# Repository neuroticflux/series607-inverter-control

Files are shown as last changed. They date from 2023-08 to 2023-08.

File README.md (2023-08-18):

# series607-inverter-control

### Overview
#### What is this?
The Series607 Inverter Control is an Arduino-based device providing data logging and remote control of a Series 607 inverter (Found in Sweden at Kjell &amp; Co under the brand LuxorParts).
The Series 607 comes with a wired control panel showing power draw on the AC side and voltage on the DC side. The device described in this repository hijacks the communication bus going to the control panel and decodes the data, then reports it via Modbus to a master device, such as a Victron Cerbo GX, or a Raspberry Pi running VenusOS. It even lets you remotely turn the inverter on or off from the touch menu, and reports alarms and fault codes like undervoltage, overvoltage, overheating etc. :)



#### Disclaimer
If you want to try this out with your own Series 607 inverter, feel free! Of course I take no responsibility for what happens to you or your hardware if you use any material or information provided in this repository. You should always be careful around high voltages and high currents. There is NO NEED to get anywhere near the AC side outlets while building this project, and there is ABSOLUTELY NO NEED to open up the inverter itself.

#### RJ12 cable pinout:
Both the pinout and color codes may very well be different on different units, so always double-check before you plug in your expensive equipment that you have your wires hooked up right!

- PIN1 (blue): power switch
- PIN2 (black): +12V
- PIN3 (red): GND
- PIN4 (green): DATA
- PIN5 (yellow): CS
- PIN6 (brown): CLK

### Instructions

#### Hardware
You need an Arduino (I've tested on Uno and the prototype runs on a Micro, likely any ATmega328-based board will work) and some RS232-to-USB bridge like an FTDI breakout board or dongle. It needs to show up in VenusOS as /dev/ttyUSB*, so using the built-in USB port on the Arduinos doesn't work. If anyone can figure out how to set VenusOS up so it scans /dev/ttyACM* as well, please let me know. :)

You also need one PNP and one NPN transistor - 2N3904 and 2N3906 work fine - and two 10kohm resistors. There's a schematic under /pcb but it's not up to date. Check the Falstad link below for a schematic of the high side switch circuit you need for remote on/off switching in VenusOS to work, the rest should be fairly self-explanatory. Pin 1 (power switch) goes to the collector of the PNP, Pin 2 (+12V) goes to the emitter.
Pins 4, 5, and 6 go to the SPI MOSI, CS and CLK pins on the Arduino, and Arduino Pin 4 goes to the base of the NPN.
If you have an Arduino Micro, you can use the hardware serial port to interface with the FTDI board. The sketch in the repo is already set up for that. If you have a Uno or some other Arduino-style board, you might need to alter the code to set up a SoftwareSerial port on two of the digital pins and connect those to the FTDI.

The circuit is simple enough to deadbug, or stick it on a protoboard with fancy pin headers if you want. :)
Burn the sketch to the Arduino and connect it to the inverter according to the pinout.

DON'T GET +12V NEAR THE GPIO LINES! It will fry your microcontroller. Yes, it's happened to me, more than once. :P

#### VenusOS
Make sure you have superuser access to your Victron device, and a way to get files onto it (wget works fine I guess).
Put the series607.py script in /opt/victronenergy/dbus-modbus-client/, then edit the dbus-modbus-client.py script in that same folder. Add this line to the list of imports:
```Python
import series607
```
Now, when you connect the interface using the RS232 dongle, a new device called 'Series607 FSW Inverter' should show up in your VenusOS menu. It may take a minute for the TTY poller to run, so be patient. ;)

If you've gotten the pinout and high-side switch right, you should now be able to control your inverter and get DC-side voltage and AC-side power showing up.

### Technical

Simulating the high side BJT switch circuit in Falstad:
https://tinyurl.com/24upg6vq

TODO: Schematics/images

### Compatibility
I've only been able to find these inverters here in Sweden, but I'd love to know if there are similar products out there with the same or similar connectivity that could be hacked in this way. Feel free to post an issue if you have a question or can provide information, or a pull request if you have something to add like code or revised/improved hardware.

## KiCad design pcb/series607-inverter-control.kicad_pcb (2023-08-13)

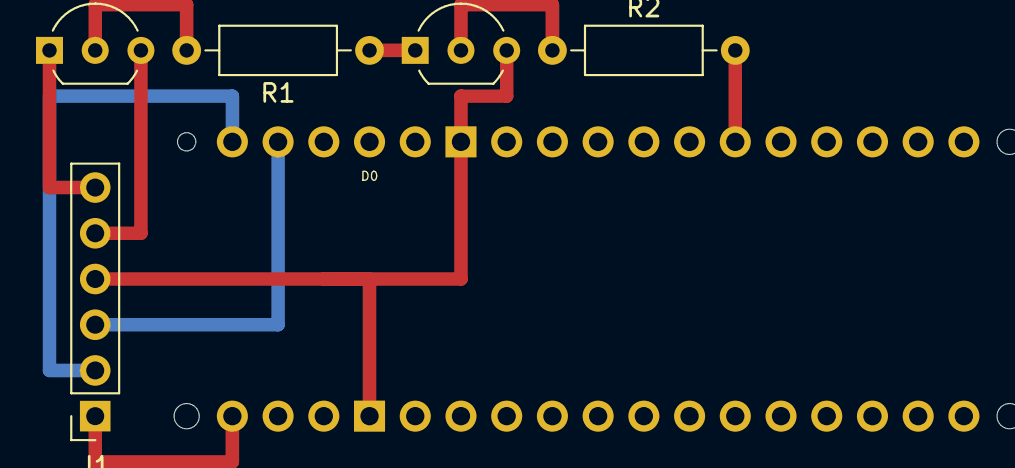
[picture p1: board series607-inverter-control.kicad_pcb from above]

Board: 2 copper layers, 6 parts (1 on the bottom side), 10 nets.

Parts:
A1: Arduino_Micro_Socket
J1: Conn_01x06_Pin; PinSocket_1x06_P2.54mm_Vertical
Q1: 2N3904; TO-92_Inline_Wide
Q2: 2N3906; TO-92_Inline_Wide
R1, R2: 10k; R_Axial_DIN0207_L6.3mm_D2.5mm_P10.16mm_Horizontal

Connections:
Arduino_GND: A1.GND1 (GND), A1.GND2 (GND), J1.4, Q1.3 (C)
Arduino_Pin_7: A1.D7 (D7_INT4), R2.2
Arduino_Pin_10: A1.SS (SPI_CS), J1.3
Arduino_Pin_11: A1.MOSI (SPI_MOSI), J1.2
Arduino_Pin_13: A1.SCK (SPI_SCK), J1.1
unnamed: J1.5, Q2.3 (C)
unnamed: J1.6, Q2.1 (E)
unnamed: Q1.2 (B), R2.1
unnamed: Q1.1 (E), R1.1
unnamed: Q2.2 (B), R1.2

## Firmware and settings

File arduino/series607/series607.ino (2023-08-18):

// Series 607 Inverter Arduino Interface
// Andy Christiansson (@neuroticflux) 2023-08-15

// Check out the repo at https://github.com/neuroticflux/series607-inverter-control for details and the latest version.

// This sketch lets an Arduino microcontroller interface with a Series 607 PSW inverter (like those sold by Kjell & Co in Sweden),
// effectively hijacking the LCD remote protocol to read power and voltage values, and, with a simple external circuit,
// allows the Arduino to remotely turn the inverter on and off.

// The interface speaks Modbus (currently over software serial port) and,
// with the accompanying Python script, can be used from a Victron Cerbo GX,
// a Raspberry Pi or other hardware running Venus OS.

// Depends on ModbusSerial by @epsilonrt, found in the Arduino IDE Library Manager, or here:
// https://github.com/epsilonrt/modbus-serial

// DISCLAIMER:
// THIS IS A HACK! USE AT YOUR OWN RISK! I have NOT tested this for safety, fire hazards etc. IT COULD BURN DOWN YOUR HOUSE/BOAT/MOTORHOME!
// I take no responsibility for what you decide to do with this code.

// GLHF! :)

#include "Arduino.h"
#include "SPI.h"
#include "ModbusSerial.h"
#include "SoftwareSerial.h"

#define SET_ADDRESS_ZERO_CMD 3

#define POWER_PIN 4

#define BUFFER_SIZE 0x100
#define BUFFER_SIZE_MASK 0xff

#define FIRMWARE_VER 0x0001
#define HARDWARE_VER 0x0001

#define SERIAL_NO 1234

#define MODEL_NO 6072

// TODO: Can we get AC voltage from Venus in case it's available and override this? Since this isn't actually
// reading a sensor it feels like a bit of a hack.
#define AC_VOLTAGE 230

// SEGMENT DISPLAY DIGIT LOOKUP TABLE
// In binary, each bit represents a segment on the 7-segment display
// The TM1721 receives an 8-bit value where the low bit is the decimal point,
// so in order to match a received 8-bit value with these segments, shift the value down 1 bit.
enum SegmentDigit {
  SEG_ZERO = 0x7d,
  SEG_ONE = 0x5,
  SEG_TWO = 0x5e,
  SEG_THREE = 0x4f,
  SEG_FOUR = 0x27,
  SEG_FIVE = 0x6b,
  SEG_SIX = 0x7b,
  SEG_SEVEN = 0x45,
  SEG_EIGHT = 0x7f,
  SEG_NINE = 0x6f,
  SEG_F = 0x72,
  SEG_OFF = 0x0,
};

// These registers are somewhat randomly picked,
// I haven't followed any conventions etc.
// Hopefully it won't cause any headaches but for now they are easily changed.
enum ModbusRegisters {
  REG_ModelNo = 0x05a0,
  REG_SerialNo = 0x1000,
  REG_HardwareVer = 0x1005,
  REG_FirmwareVer,

  REG_DCVoltage = 0x3001,
  REG_ACVoltage, // The inverter isn't measuring AC volts, but we might want to add functionality for it eventually. For now we just fake it by sending AC_VOLTAGE whenever the inverter is on.
  REG_Current,
  REG_Power,
  REG_Mode,
  REG_State,
  REG_AlarmLowVoltage = 0x3010,
  REG_AlarmHighVoltage,
  REG_AlarmOverload,
  REG_AlarmHighTemperature,
};

// Translate TM1721 LCD segment data to digits
static inline int8_t SegmentDataToDigit(uint8_t data)
{
  switch(data) {
    case SEG_OFF: return 0;
    case SEG_ZERO: return 0;
    case SEG_ONE: return 1;
    case SEG_TWO: return 2;
    case SEG_THREE: return 3;
    case SEG_FOUR: return 4;
    case SEG_FIVE: return 5;
    case SEG_SIX: return 6;
    case SEG_SEVEN: return 7;
    case SEG_EIGHT: return 8;
    case SEG_NINE: return 9;
    default: return -1;
  }
}

enum DisplayMode
{
  DM_Power = 0,
  DM_Voltage,
};

// These match the Victron inverter state values according to (https://github.com/victronenergy/venus/wiki/dbus)
enum PowerState
{
  State_Off = 0,
  State_LowPower = 1,
  State_Fault = 2,
  State_Inverting = 9,
};

// Again, these match Victron's values, for simplicity
enum PowerMode
{
  Mode_On = 2,
  Mode_Off = 4,
//  Mode_Eco = 5, // Victron are using this but obviously we don't support it
};

enum FaultCode {
  Fault_NoFault = 0,
  Fault_UnderVoltage,
  Fault_OverVoltage,
  Fault_Overload,
  Fault_Overheat,
  Fault_ShortCircuit,
};

enum FaultLevel {
  FaultLevel_OK = 0,
  FaultLevel_Warning,
  FaultLevel_Alarm
};

PowerState powerState; // Purely reactive state, never set this explicitly from client/UI
PowerMode powerMode; // Controlling state, this is either set explicitly via Modbus or reactively when the inverter is turned on externally

DisplayMode displayMode; // Keep track of the LCD "page" - a fast button press switches between the DC (voltage) and AC (power) display

volatile uint8_t buffer[BUFFER_SIZE];

volatile uint8_t head = 0;
volatile uint8_t tail = 0;

// TODO: These are actually not in millis, decide what to do here.
//       With 16-bit registers using millis is a bit tight, so this
//       is probably fine, but they will have to be scaled by client

int32_t voltage = 0; // Millivolts
int32_t  current = 0; // Milliamps
int32_t power = 0; // Milliwatts

// Flag to keep an eye on SPI activity
volatile uint8_t didReceiveSPI = 0;

// Timing
uint32_t keepAliveTimer = 0;
uint32_t keepAlivePeriod = 700000; //us

uint32_t displaySwitchTimer = 0;
uint32_t displaySwitchPeriod = 1000000; //us

// TODO: Alarms (follow Victron specs)
FaultCode faultCode = Fault_NoFault;

// Buffer for SPI messages
uint8_t message[8];

// Arduino Micro has hardware serial on Serial1, the built-in USB serial is software
// and doesn't work with VenusOS (it shows up as ttyACM* instead of ttyUSB*).
// So we can't use the USB port on the Micro for Modbus, but for now
// we'll use an FTDI breakout board on Serial1 and eventually maybe move to a custom PCB.
ModbusSerial modbus(Serial1, 42);

// SPI interrupt
ISR(SPI_STC_vect)
{
  buffer[++head & BUFFER_SIZE_MASK] = SPDR;
  didReceiveSPI = 1;
}

// Some helper functions to control state
void ModeOn()
{
  head = 0;
  tail = 0;
  powerMode = Mode_On;
  modbus.setHreg(REG_Mode, Mode_On);
}

void ModeOff()
{
  powerMode = Mode_Off;
  modbus.setHreg(REG_Mode, Mode_Off);
}

void SwitchDisplay()
{
  SPI.detachInterrupt();
  head = 0;
  tail = 0;
  ShortPress();
  SPI.attachInterrupt();
}

void DoPressDown()
{
  digitalWrite(POWER_PIN, HIGH);
}

void DoPressUp()
{
  digitalWrite(POWER_PIN, LOW);
}

void ShortPress()
{
  digitalWrite(POWER_PIN, HIGH);
  delay(200);
  digitalWrite(POWER_PIN, LOW);
}

// TODO: Maybe try doing just a warning on overload and alarm on short circuit using the Overload register, since there's no short circuit alarm on VenusOS
void UpdateAlarms()
{
  // This is quite ugly but for now it works. The more I work with this modbus lib the less I like it...
  // TODO: Should really look into rolling our own or replace it.
  // Iterate all the alarms and reset every code except the one that was triggered.
  modbus.setHreg(REG_AlarmLowVoltage, faultCode == Fault_UnderVoltage ? FaultLevel_Alarm : FaultLevel_OK);
  modbus.setHreg(REG_AlarmHighVoltage, faultCode == Fault_OverVoltage ? FaultLevel_Alarm : FaultLevel_OK);
  modbus.setHreg(REG_AlarmOverload, faultCode == Fault_Overload ? FaultLevel_Alarm : FaultLevel_OK);
  modbus.setHreg(REG_AlarmHighTemperature, faultCode == Fault_Overheat ? FaultLevel_Alarm : FaultLevel_OK);
  modbus.setHreg(REG_AlarmOverload, faultCode == Fault_ShortCircuit ? FaultLevel_Alarm : FaultLevel_OK); // VenusOS doesn't support the short circuit fault code, so we'll set overload instead
}

void setup() {

  // Enable internal pullup resistor on SS line, in case the device is disconnected from the inverter we don't want garbage data in the SPI buffer
  pinMode(SS, INPUT_PULLUP);

  // Set up power on/mode switch pin
  pinMode(POWER_PIN, OUTPUT);
  digitalWrite(POWER_PIN, LOW);

  // Zero data buffer
  head = 0;
  tail = 0;

  // SPI slave mode on
  SPCR |= _BV(SPE);
  SPDR = 0; // Zero the SPI data register so we can check if data arrived

  SPI.setClockDivider(SPI_CLOCK_DIV2);
  SPI.attachInterrupt();

  // TODO: Proper debug #define and dummy functions for debug/release builds
  Serial.begin(115200);

  // TODO: Dip switches to set baud rate?
  Serial1.begin(38400);

  delay(500);

  Serial.print("Series607 Interface starting up... ");
  modbus.config(38400);
  
  // TODO: Figure out if this is useful for anything
  modbus.setAdditionalServerData("TEST");

  // Start in off state
  powerState = State_Off;
  powerMode = Mode_Off;

  // Set up Modbus registers
  // NOTE: For now everything is holding registers, it looks like Venus defaults to sending the Modbus 0x3 command (Read Holding Register) no matter what,
  // and uses a flag in the driver to signify read-only vs read/write registers. See the Python script.
  modbus.addHreg(REG_ModelNo, MODEL_NO);
  
  // TODO: Fix serial number registers
  modbus.addHreg(REG_SerialNo + 0, 'A' >> 8 & 'B');
  modbus.addHreg(REG_SerialNo + 1, 'C' >> 8 & 'D');
  modbus.addHreg(REG_SerialNo + 2, 'E' >> 8 & 'F');

  // TODO: Proper version numbers and decoding on Venus
  modbus.addHreg(REG_HardwareVer, HARDWARE_VER);
  modbus.addHreg(REG_FirmwareVer, FIRMWARE_VER);

  // Actual device stats and alarms/warnings
  modbus.addHreg(REG_DCVoltage);
  modbus.addHreg(REG_ACVoltage);
  modbus.addHreg(REG_Current);
  modbus.addHreg(REG_Power);

  modbus.addHreg(REG_State, powerState);
  modbus.addHreg(REG_Mode, powerMode);

  modbus.addHreg(REG_AlarmLowVoltage, 0);
  modbus.addHreg(REG_AlarmHighVoltage, 0);
  modbus.addHreg(REG_AlarmOverload, 0);
  modbus.addHreg(REG_AlarmHighTemperature, 0);

  // TODO: Fault alarm registers

  // Short delay to allow SPI to arrive, in case the inverter is already on
  delay(500);
  
  Serial.println("Ready.");
}

int32_t CalculateCurrent(int32_t power) {

  // Some fixed-point math to avoid floats
  int32_t voltage = AC_VOLTAGE * 10;
  power *= 1000;

  return (power / voltage); // One division is fine, just don't get comfortable using them on the 328... :p
}

// Flag when we get an actual data packet, not commands
uint8_t receivingData = 0;

// Track current address of data being written
uint8_t address = 0;

void loop() {
  
  modbus.task();

  uint8_t data = 0;
  uint8_t _head = head; // Cache the current buffer head locally (so the ISR can safely cut in here and write new SPI data)

  // NOTE/TODO ON DATA TRANSFERS
  // For unknown reasons, not all data seems to be received. Looking at the logic analyzer, there seems to be a few bytes after the main data packet which the Arduino doesn't pick up.
  // Need to research this further, but as long as we can get out relevant data, it doesn't matter for now.

  // MESSAGE BUFFER ADDRESSES:
  // 00h: State of charge, battery indicator
  // 01h: First digit (high byte is dot)
  // 02h: Second digit
  // 03h: Third digit (high byte is <probably> AC/DC indicator?)
  // 04h: Battery percentages
  // 05h: Battery percentages

  // TODO: Nail down which bit is the AC/DC indicator and battery indicator frame - the latter is blinking at startup, should be possible to spot

  // While there's data in the buffer, get the next byte
  while (_head != tail) {

    data = buffer[++tail & BUFFER_SIZE_MASK];

    // TODO: Clean this up, functionize etc
    switch(data) {

    // Got set address 0 command, so let's start receiving
    case SET_ADDRESS_ZERO_CMD:
      receivingData = 1;
      address = 0;
      continue; // Skip the current command byte

    default: break;
    }

    // We're currently receiving data, so compose the message one byte at a time
    if (receivingData == 1) {
      message[address++] = data;
    }

    // Received complete message (6 bytes), let's process
    if (address > 5) {
      // Is the mode Watts or Voltage? Check the dot bit on 03h to find out

      displayMode = (DisplayMode)(message[3] & 0x1);

      // TODO: Detect unknown segment data (SegmentDataToDigit() returns -1) and handle

      // FAULT CODES:
      // F01: Low input voltage
      // F02: High input voltage
      // F03: AC-side current overload
      // F04: High temperature
      // F05: AC-side short circui

      // Assume no fault...
      faultCode = Fault_NoFault;

      //...then falsify
      if(message[1] >> 1 == SEG_F) {
        faultCode = (FaultCode)SegmentDataToDigit(message[3] >> 1);
        UpdateAlarms();
      }

      else if (displayMode == DM_Voltage) {
        // Compose DC voltage result (in mV)
        voltage = SegmentDataToDigit(message[3] >> 1) * 100;
        voltage += SegmentDataToDigit(message[2] >> 1) * 1000;
        voltage += SegmentDataToDigit(message[1] >> 1) * 10000;

      } else {
        // TODO: Look into 32-bit register by using two regs for one value, but might be easier with own/other modbus lib
        power = SegmentDataToDigit(message[3] >> 1) * 1;
        power += SegmentDataToDigit(message[2] >> 1) * 10;
        power += SegmentDataToDigit(message[1] >> 1) * 100;
      }

      // Message handled, reset state
      receivingData = 0;
      address = 0;
    }
  }
  // When we're done processing messages, do higher level stuff

  // Set fault state if we detected a fault
  if(faultCode != Fault_NoFault) {
    powerState = State_Fault;
  }

  uint32_t t = micros();

  // Check the mode register, should we power up/down?
  switch((PowerMode)modbus.hreg(REG_Mode)) {
    case Mode_On: {
      // If the mode is On and the inverter is currently off, and not in fault mode, press the button
      // TODO: Timeout, don't want to indefinitely press the button if something's wrong
      if(powerState == State_Off) {
        DoPressDown();
      } else {
        DoPressUp();
      }
    } break;

    case Mode_Off: {
      // If the mode is Off and the inverter isn't off, press the button
      if(powerState != State_Off) {
        DoPressDown();
      } else {
        DoPressUp();
      }
    } break;
  }

  // FSM
  switch(powerState) {

    case State_Off: {
      voltage = 0;
      power = 0;
      current = 0;

      // TODO: Turning off is slightly unreliable because setting the mode switch line high activates SPI,
      // and because we're still using the power pin to switch display mode, the device thinks that the inverter turned back on,
      // then off again when keepAlive times out.
      // Easiest solution is probably to have some grace period after changing power state before we allow switching the display mode.
      // Seems we're also receiving some garbage data packets when this happens, sometimes the voltage will report as several hundred volts for example,
      // so it's probably a good idea for several reasons.
      if (didReceiveSPI == 1) {
        // The inverter turned on, so we should change state. Are we generating power?
        if(power > 0) {
          powerState = State_Inverting;
        } else {
          powerState = State_LowPower;
        }
        Serial.println("Inverter turned on.");
        ModeOn();
      }
    } break;

    // Inverter on, set state, switch display etc
    case State_LowPower:
    case State_Inverting:
    
      // Ask inverter to switch display mode on the LCD (to sniff both DC voltage and AC power values)
      if(t - displaySwitchTimer > displaySwitchPeriod && powerMode != Mode_Off) {
        SwitchDisplay();
        displaySwitchTimer = t;

        // TODO: Proper debug mode
//        Serial.print("Voltage: ");
//        Serial.println(voltage);
//        Serial.print("Current: ");
//        Serial.println(current);
//        Serial.print("Power: ");
//        Serial.println(power);
      }

    // On-states fall through to State_Fault so we can skip switching displays in fault mode (button presses have no effect) but still do keepalive in one place
    case State_Fault:
      // Clear fault state and set correct state according to power usage
      if (faultCode == Fault_NoFault) {
        UpdateAlarms();
        powerState = power > 0 ? State_Inverting : State_LowPower;
      }
      // If we've received at least one SPI message, reset keepalive, otherwise count down
      if (didReceiveSPI == 1) {
        keepAliveTimer = t;
        didReceiveSPI = 0;

      } else if (t - keepAliveTimer > keepAlivePeriod) {
        keepAliveTimer = 0;
        Serial.println("Inverter turned off.");
        powerState = State_Off;
        ModeOff();
      }
    break;
  }

  // Update data registers
  current = CalculateCurrent(power);

  modbus.setHreg(REG_DCVoltage, voltage);
  modbus.setHreg(REG_ACVoltage, powerState != State_Off ? AC_VOLTAGE : 0);
  modbus.setHreg(REG_Power, power);
  modbus.setHreg(REG_Current, current);
  modbus.setHreg(REG_State, powerState);
}

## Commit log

2023-08-13 Added KiCad protoboard project
    [series607-inverter-control.kicad_pcb, series607-inverter-control.kicad_sch]
2023-08-17 Changes to support Arduino Micro
2023-08-18 Device firmware supports alarms
2023-08-18 Correct power multiplier
